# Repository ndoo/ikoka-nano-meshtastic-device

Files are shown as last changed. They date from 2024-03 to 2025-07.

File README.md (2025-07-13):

# Ikoka Nano Meshtastic Device

A Meshtastic device based on the [Seeed Studio XIAO nRF52840](https://www.seeedstudio.com/Seeed-XIAO-BLE-nRF52840-p-5201.html) and EBYTE E22-XXXMXXS series LoRa modules. Pinout matches the [Meshtastic xiao_ble variant](https://github.com/meshtastic/firmware/tree/master/variants/xiao_ble).

The focus is on small size without an onboard display or buttons, meaning it must be used with [Meshtastic client software](https://meshtastic.org/docs/software/), or as a remote repeater managed with [remote node administration](https://meshtastic.org/docs/configuration/remote-admin/).

## Connectors

* USB-C for power and data
* Qwiic connector for I²C sensors
* Battery connectors (PicoBlade 1.25-2P)
* Solar connector (PicoBlade 1.25-2P, 4.45 to 6.45 V - BQ25100 charge IC)

## Libraries Used

* [SnapMagic E22-900M30S footprint & symbol](https://www.snapeda.com/parts/E22-900M30S/EBYTE/view-part/)
* [SparkFun KiCad Libraries](https://github.com/sparkfun/SparkFun-KiCad-Libraries)
* [SeeedStudio OPL KiCad Library](https://github.com/ndoo/OPL_Kicad_Library/tree/xiao-ble-symbols) (forked to add missing XIAO nRF5240 symbol)

## Building One

### Software Required

* The files were created in [KiCad](https://www.kicad.org/) 8
* Clone this git repository recursively, i.e. with `--recursive`

### Ordering PCBs

* Generate the production files
  * Install [kicad-jlcpcb-tools](https://github.com/Bouni/kicad-jlcpcb-tools)
  * Open the PCB file
  * Tools -> External Plugins -> JLCPCB Tools
  * Look over the Bill of Materials list and perform any substitutions required
  * Click Generate
* Order the PCBs
  * Use the Gerbers, BOM and CPL files in `jlcpcb/production_files`
  * Default 1.6mm 2-layer PCB settings should work well, this PCB passes DRC based on JLCPCB specifications (other than the silkscreen of XIAO module being clipped by the PCB edge)

### Ordering Components

* Check the exported BOM file in `jlcpcb/production_files`

### Assembling the PCB

I suggest PCBA, but I used handsoldering pads and all SMDs are 0603 or larger so can be hand-soldered.

1. Solder the SMD components
   * The larger (0805) capacitors go closer to the USB-C connector end of the PCB
2. Solder the connectors
3. Solder the XIAO BLE
   1. It helps to tin the BAT+ pad first, it will help ensure successful soldering through the back. Remove excess solder so that the pad is flat, otherwise the XIAO will not sit flush
   2. Solder one pad first then verify all pads and the battery hole are lined up well, adjust the alignment if necessary
   3. Solder one more pad diagonally opposite, double check the alignment of the pads
   4. Solder the rear hole that goes to the BAT+ pad
   5. Solder the rest of the pads
   6. Test that the XIAO is able to power up from the battery and that charging works (a yellow LED will light up if the battery is charging), you won't be able to access the BAT+ pad once the E22 module is soldered
4. Solder the E22-900M30S module

### Flashing Meshtastic Firmware

#### Pre-built Binaries (Unofficial)

1. [Custom Meshtastic builds web installer](https://mrekin.duckdns.org/flasher/)
2. Select your device -> Xiao BLE
3. Select firmware version -> Pick the latest release
4. Select update or reinstall -> Update device (usually works fine, but if Meshtastic does not start after a few seconds, wipe and reinstall)
5. Download UF2
6. Connect USB-C to PC, double-tap the reset button
7. Drop UF2 file into XIAO-SENSE USB volume

#### Building from Source

Follow the instructions at [meshtastic/firmware/variants/diy/xiao_ble/](https://github.com/meshtastic/firmware/tree/master/variants/diy/xiao_ble).

### Enclosure

A snap-fit 3D printable enclosure is available in the `enclosures` folder. **This has not been updated for the latest board design ([2b17a53](https://github.com/ndoo/ikoka-nano-meshtastic-device/commit/2b17a53b4cfc0f9a9a845ffaf8d8353723f1d552)).**

## PCB Images

rotating

top
bottom

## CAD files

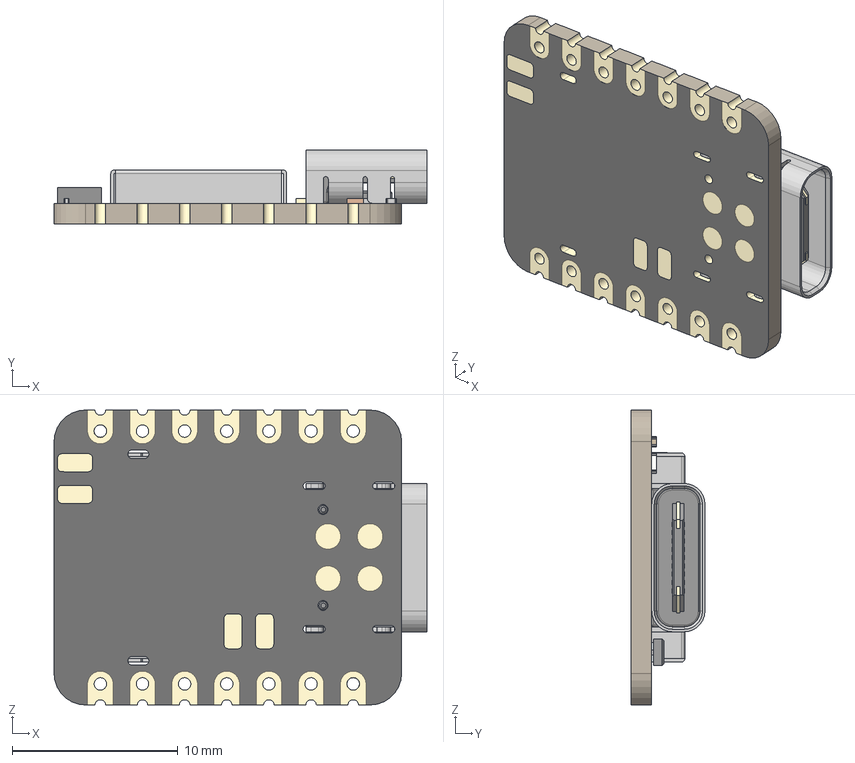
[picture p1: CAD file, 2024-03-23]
3dmodels/XIAO-nRF52840 v15.step
22.5 x 4.46 x 17.8 mm
BOSS-EXTRUDE14_8_
BOSS-EXTRUDE7_4_
BOSS-EXTRUDE7_3_
BOSS-EXTRUDE14_4_
BOSS-EXTRUDE14_2_
BOSS-EXTRUDE14_11_
BOSS-EXTRUDE7_7_
BOSS-EXTRUDE14_9_
BOSS-EXTRUDE14_3_
BOSS-EXTRUDE14_7_
MIRROR2
BOSS-EXTRUDE14_5_
BOSS-EXTRUDE14_12_
BOSS-EXTRUDE7_8_
BOSS-EXTRUDE7_1_
BOSS-EXTRUDE14_10_
BOSS-EXTRUDE7_9_
BOSS-EXTRUDE14_6_
BOSS-EXTRUDE14_1_
BOSS-EXTRUDE7_6_
BOSS-EXTRUDE7_2_
CUT-EXTRUDE5
BOSS-EXTRUDE7_5_
Shield
Pins
CAP x 2
ANT1
Silkscreen
CAP 3
LED
USR
2 v1

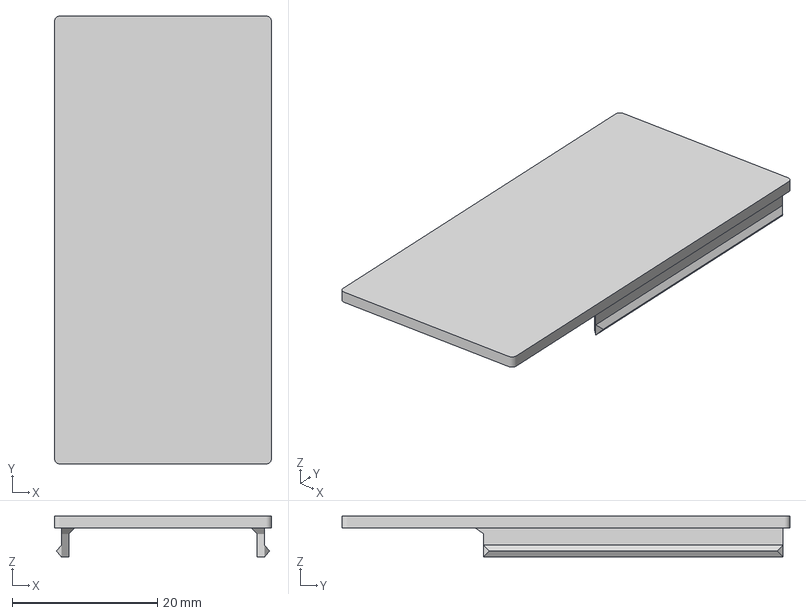
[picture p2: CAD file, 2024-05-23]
enclosure/ikoka nano enclosure lid.3mf
29.9 x 61.7 x 5.60 mm

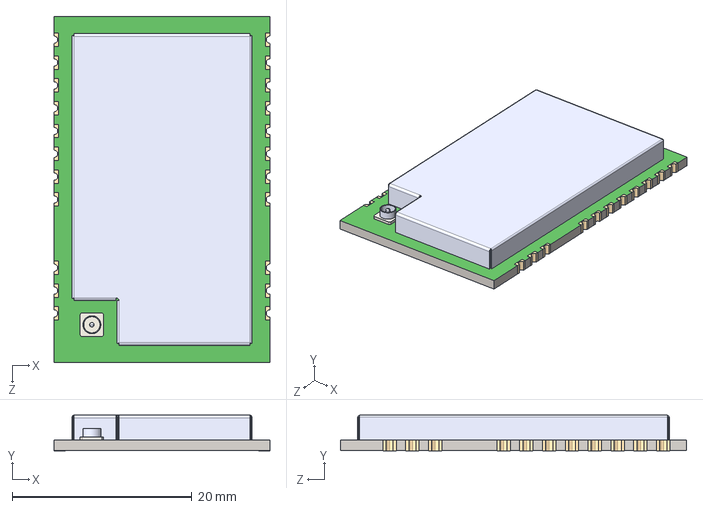
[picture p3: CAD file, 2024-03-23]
symbols/E22-900M30S/E22-900M30S.step
24.0 x 3.97 x 38.5 mm

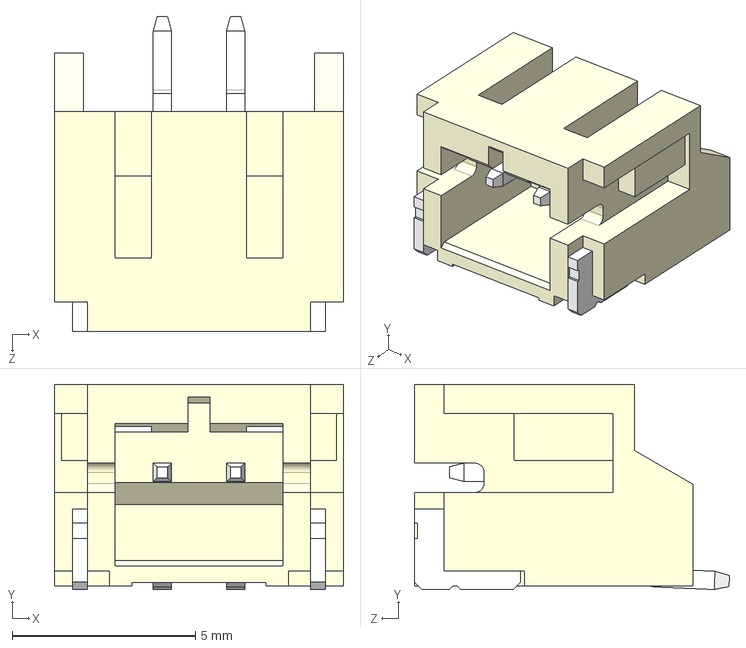
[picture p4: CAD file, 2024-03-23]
3dmodels/S2B-PH-SM4-TB--3DModel-STEP-269445.STEP
7.90 x 5.60 x 8.60 mm

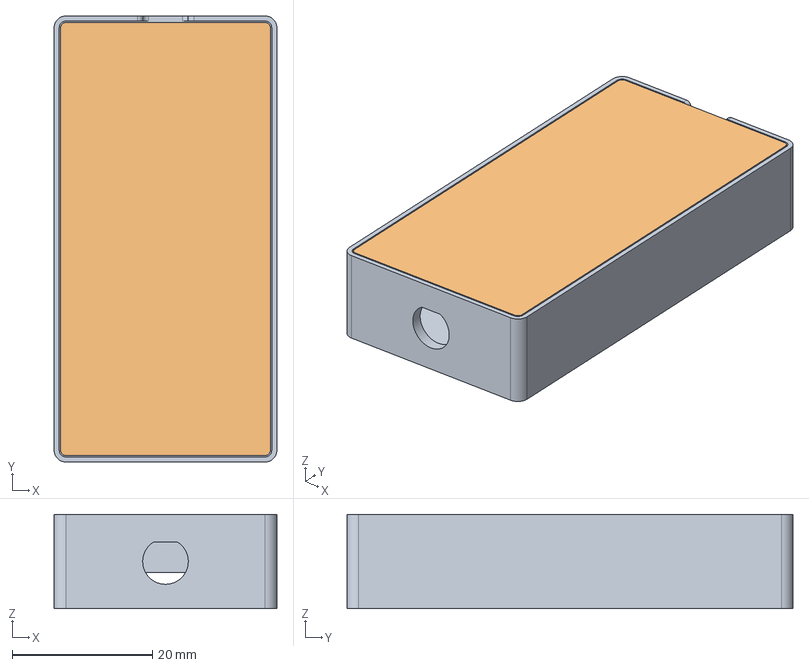
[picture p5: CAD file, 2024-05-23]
enclosure/ikoka nano enclosure.step
31.7 x 63.5 x 13.4 mm

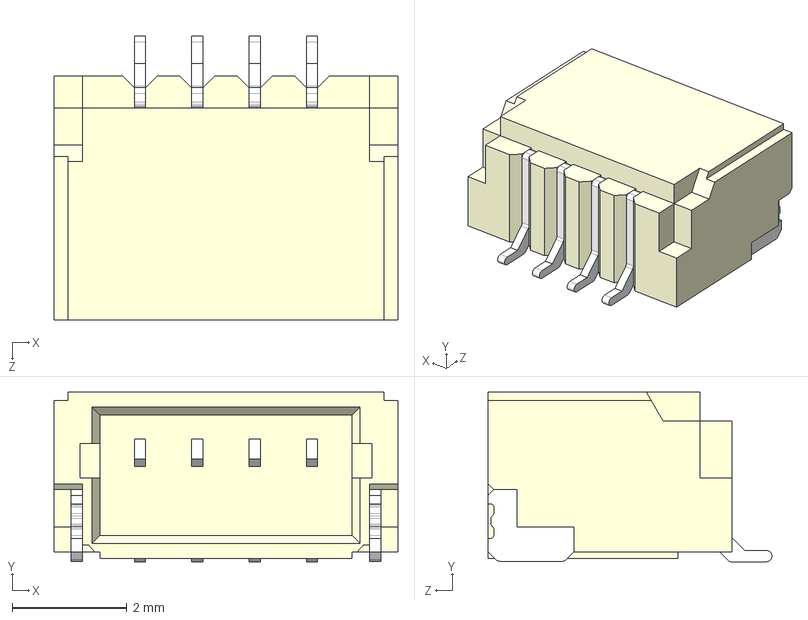
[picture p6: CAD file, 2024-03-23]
3dmodels/SM04B-SRSS-TB(LF)(SN)--3DModel-STEP-269445.STEP
6.00 x 2.96 x 4.95 mm

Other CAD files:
enclosure/ikoka nano enclosure lid.stl
enclosure/ikoka nano enclosure.3mf
enclosure/ikoka nano enclosure.f3d
enclosure/ikoka nano enclosure.stl

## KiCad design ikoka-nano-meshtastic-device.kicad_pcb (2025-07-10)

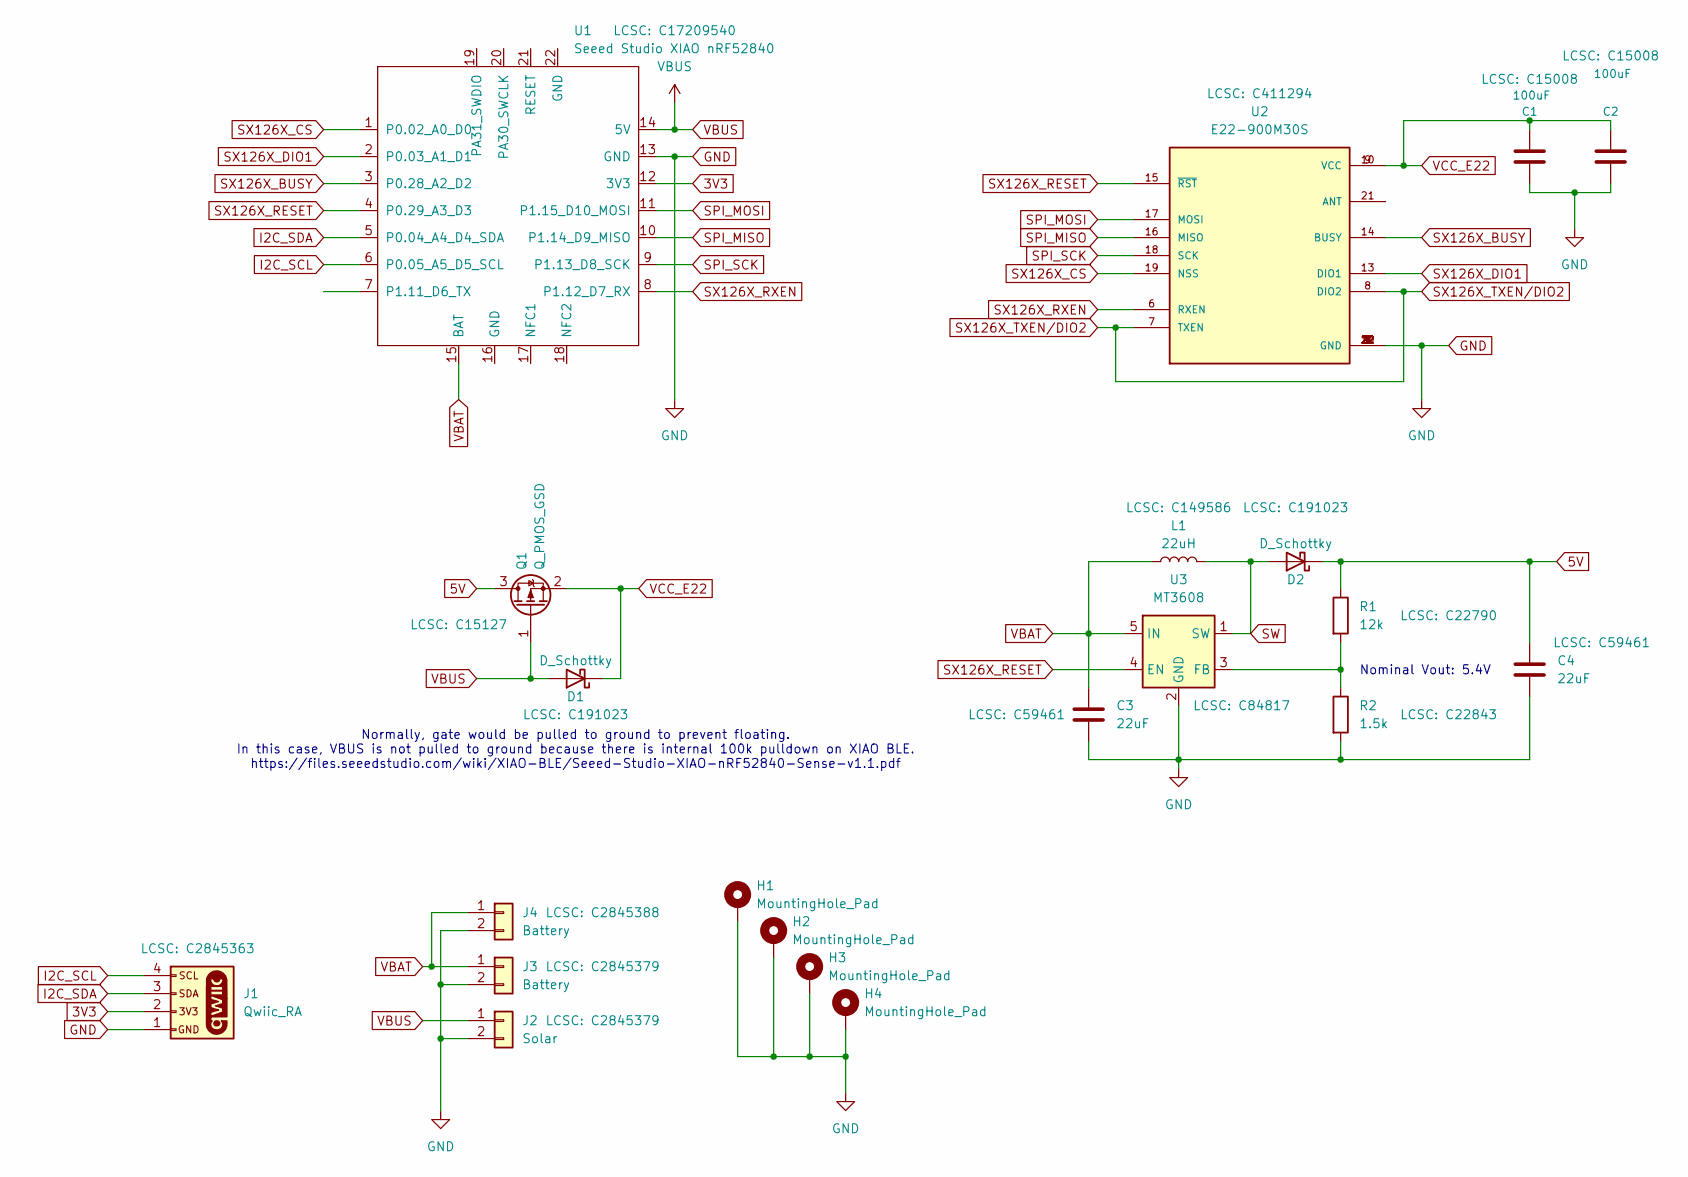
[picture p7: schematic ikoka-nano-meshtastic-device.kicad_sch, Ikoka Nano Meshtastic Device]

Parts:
C1, C2: 100uF; C_1206_3216Metric_Pad1.33x1.80mm_HandSolder; MPN CL31A107MQHNNNE; LCSC C15008
C3, C4: 22uF; C_0603_1608Metric_Pad1.08x0.95mm_HandSolder; MPN CL10A226MQ8NRNC; LCSC C59461
D1, D2: D_Schottky; D_SOD-323_HandSoldering; LCSC C191023
H1, H2, H3, H4: MountingHole_Pad; MountingHole_2.7mm_M2.5_Pad_Via
J1: Qwiic_RA; JST_SMD_1.0mm-4_Black; LCSC C2845363
J2: Solar; Molex_PicoBlade_53261-0271_1x02-1MP_P1.25mm_Horizontal; LCSC C2845379
J3: Battery; Molex_PicoBlade_53261-0271_1x02-1MP_P1.25mm_Horizontal; LCSC C2845379
J4: Battery; Molex_PicoBlade_53398-0271_1x02-1MP_P1.25mm_Vertical; LCSC C2845388
L1: 22uH; L_SXN_SMDRI64; MPN SMMS0650-220M; LCSC C149586
Q1: Q_PMOS_GSD; SOT-23_Handsoldering; LCSC C15127
R1: 12k; R_0603_1608Metric_Pad0.98x0.95mm_HandSolder; MPN 0603WAF1502T5E; LCSC C22790
R2: 1.5k; R_0603_1608Metric_Pad0.98x0.95mm_HandSolder; MPN 0603WAF1871T5E; LCSC C22843
U1: Seeed Studio XIAO nRF52840; XIAO-nRF52840-SMD_Handsoldering; LCSC C17209540
U2: E22-900M30S; XCVR_E22-900M30S; PARTREV 1.2; LCSC C411294
U3: MT3608; SOT-23-6; LCSC C84817

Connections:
3V3: J1.2, U1.12 (3V3)
5V: C4.1, D2.1 (K), Q1.3 (D), R1.1
GND: C1.1, C2.1, C3.2, C4.2, H1.1, H2.1, H3.1, H4.1, J1.1, J2.2, J3.2, J4.2, R2.2, U1.13 (GND), U2.1 (GND), U2.2 (GND), U2.3 (GND), U2.4 (GND), U2.5 (GND), U2.11 (GND), U2.12 (GND), U2.20 (GND), U2.22 (GND), U3.2 (GND)
I2C_SCL: J1.4, U1.6 (P0.05_A5_D5_SCL)
I2C_SDA: J1.3, U1.5 (P0.04_A4_D4_SDA)
unnamed: R1.2, R2.1, U3.3 (FB)
SPI_MISO: U1.10 (P1.14_D9_MISO), U2.16 (MISO)
SPI_MOSI: U1.11 (P1.15_D10_MOSI), U2.17 (MOSI)
SPI_SCK: U1.9 (P1.13_D8_SCK), U2.18 (SCK)
SW: D2.2 (A), L1.2, U3.1 (SW)
SX126X_BUSY: U1.3 (P0.28_A2_D2), U2.14 (BUSY)
SX126X_CS: U1.1 (P0.02_A0_D0), U2.19 (NSS)
SX126X_DIO1: U1.2 (P0.03_A1_D1), U2.13 (DIO1)
SX126X_RESET: U1.4 (P0.29_A3_D3), U2.15 (~RST), U3.4 (EN)
SX126X_RXEN: U1.8 (P1.12_D7_RX), U2.6 (RXEN)
SX126X_TXEN/DIO2: U2.7 (TXEN), U2.8 (DIO2)
VBAT: C3.1, J3.1, J4.1, L1.1, U1.15 (BAT), U3.5 (IN)
VBUS: D1.2 (A), J2.1, Q1.1 (G), U1.14 (5V)
VCC_E22: C1.2, C2.2, D1.1 (K), Q1.2 (S), U2.9 (VCC), U2.10 (VCC)

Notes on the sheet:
Nominal Vout: 5.4V
Normally, gate would be pulled to ground to prevent floating. In this case, VBUS is not pulled to ground because there is internal 100k pulldown on XIAO BLE. https://files.seeedstudio.com/wiki/XIAO-BLE/Seeed-Studio-XIAO-nRF52840-Sense-v1.1.pdf

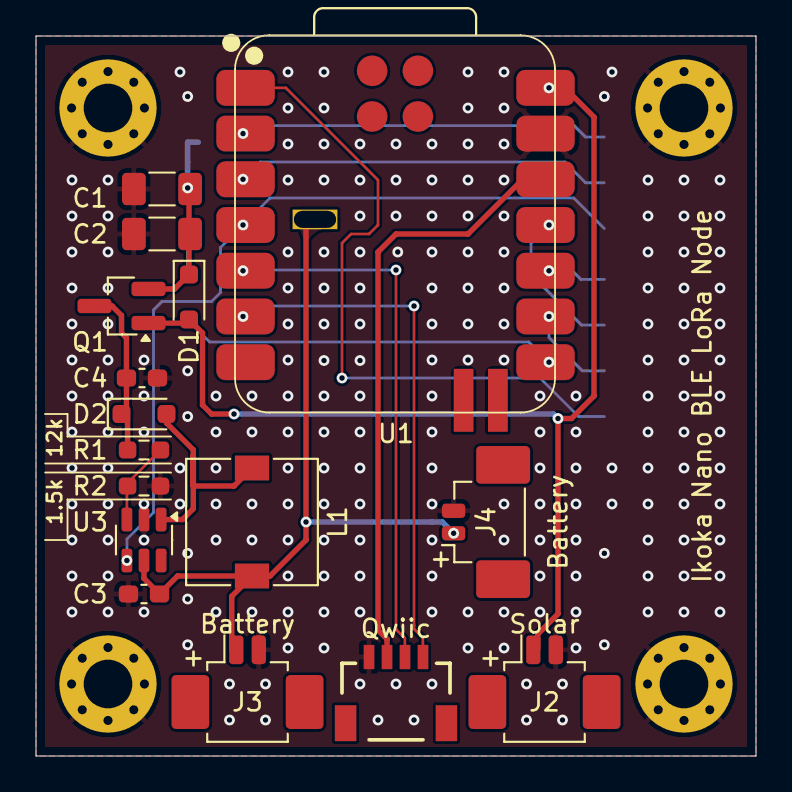
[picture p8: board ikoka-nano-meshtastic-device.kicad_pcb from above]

Board: 2 copper layers, 40.0 x 40.0 mm, 21 parts (1 on the bottom side), 19 nets.

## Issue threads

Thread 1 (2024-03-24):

5V boost regulator for rated output power of E22 module

ndoo, 2024-03-24:
Run the E22 module off a boost converter from VBAT so that E22 PA can achieve full output power. Not sure this will fit in the board footprint though,.

Closed 2025-01-14.

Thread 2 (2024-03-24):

Add cutout to route antenna of E22 to front side

ndoo, 2024-03-24:
Add cutout to route antenna of E22 to front side, for enclosures that will have the E22 module flush to the back of the chassis

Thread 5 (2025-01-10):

Add scematic and other exports for import in Easyeda for self-modifications

tokio69, 2025-01-10:
I want to add some power possibilities to the board, please open the scematic and other files needed to import it in Easyeda

ndoo, 2025-01-10:
Everything you need is in this repository.

tokio69, 2025-01-10:
Not the scematic? Where is that? I only find the Gerber

ndoo, 2025-01-10:
It also says right here in the README that KiCad is required software for this project.

https://github.com/ndoo/ikoka-nano-meshtastic-device?tab=readme-ov-file#software-required

tokio69, 2025-01-11:
Great, I found it to import in EasyEda, just did not know that SCH was the KiCAD file extension for the project since i never used that. This is awesome so thank you

Closed 2025-01-10.

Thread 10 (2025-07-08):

Flashing instructions

tremmert81-tx, 2025-07-08:
Your link to the flashing instructions is not valid:

Follow the instructions at [meshtastic/firmware/variants/xiao_ble/](https://github.com/meshtastic/firmware/tree/master/variants/xiao_ble).

Can you provide the correct link that we should follow?

ndoo, 2025-07-09:
Hi there,

The link broke because of some cleanup in Meshtastic firmware I did.

Here is where the file has moved:

https://github.com/meshtastic/firmware/blob/master/variants/diy/xiao_ble/README.md

I'm not sure if that README is still up-to-date though.

If you already have a build device, what you need to do is download the source of the release that you want on the Meshtastic firmware repo releases page, open it in VS code/PlatformIO, select the xiao_ble variant and build it.

The UF2 file for the firmware can then be found in .pio/build.

Connect the XIAO to your PC and double tap the reset button of the XIAO, a USB disk will appear and you drop the UF2 file in there.

I'll find time to update the README here and in the Meshtastic firmware repo.

ndoo, 2025-07-09:
Hi there @tremmert81-tx,

The README.md in the upstream firmware is very out of date, I have made some improvements to it and raised a PR https://github.com/meshtastic/firmware/pull/7283 to have these changes upstreamed.

You can take a look at my new README.md for xiao_ble here, at least, until it gets accepted into upstream, at which point I may delete my branch: https://github.com/ndoo/meshtastic-firmware/blob/xiao_ble-readme/variants/diy/xiao_ble/README.md

Once it's merged into upstream, I'll update the link in this repo.

Thanks for your patience.

Closed 2025-07-13.

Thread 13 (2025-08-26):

Compatibilty with 33S modules

KevinGaudry, 2025-08-26:
Hello,

First of all, thanks for the work done, looks tidy.

I was reading some other projects and there was a step to take care of when using this 33db module, reducing power to 9db during first setup.
Is this still the case or has this been fixed in code ? I am not qualified enough to check unfortunately...

Other than this, the PCB files and CPL+BOM which I can download in the latest version are just good to go or shall I wait another release ?

Thanks for the support,
Kevin

ndoo, 2025-08-26:
It's taken care of in code, use the firmware variant that ends in 900m33s; you can build it yourself or obtain binaries here: https://mrekin.duckdns.org/flasher/

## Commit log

2024-03-23 Redesign board because the E22-900M22S footprint from SnapMagic was much smaller than the actual module size; add solar 5V connector; reduce Qwiic connectors to just one.
    [ikoka-nano.brd, ikoka-nano.sch]
2024-03-23 Update README and add PCB images
2024-03-23 Add project name and ndoo.sg to board front
    [ikoka-nano.brd]
2024-03-23 Move some values to names layer to ensure JLCPCB CAM generates silkscreen; hide U1/U2 value under components
    [ikoka-nano.brd]
2024-03-23 Update PCB images
2024-03-23 Update schematic with LCSC part numbers
    [ikoka-nano-meshtastic-device.kicad_pcb, ikoka-nano-meshtastic-device.kicad_sch]
2024-03-23 Update board images to be non-perspective views
2024-03-23 Add generated Gerbers/BOM for JLCPCB
    [ikoka-nano-meshtastic-device-B_Cu.gbl, ikoka-nano-meshtastic-device-B_Mask.gbs, ikoka-nano-meshtastic-device-B_Paste.gbp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]
2024-03-23 Update ground plane stitching and related generated artifacts; bump PCB revision to 1.1
    [ikoka-nano-meshtastic-device-B_Cu.gbl, ikoka-nano-meshtastic-device-B_Mask.gbs, ikoka-nano-meshtastic-device-B_Paste.gbp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]
2024-05-09 Power EBYTE E22 module from 5V and remove JST-PH 2.0 connectors
    Power EBYTE E22 module from 5V because VBAT results in very poor transmit power.
    Remove JST connectors since the device no longer functions without 5V.
    [ikoka-nano-meshtastic-device.kicad_pcb, ikoka-nano-meshtastic-device.kicad_sch]
2024-05-09 Update footprints table
2024-05-09 Add kicad-render GitHub action
    Add kicad-render GitHub action from [linalinn/kicad-render](https://github.com/linalinn/kicad-render)
    [ikoka-nano-meshtastic-device-B_Cu.gbl, ikoka-nano-meshtastic-device-B_Mask.gbs, ikoka-nano-meshtastic-device-B_Paste.gbp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]
2024-05-09 Update README for KiCad 8 and rendered images
2024-05-09 Update .gitignore to ignore KiCad 8 lock files
2024-05-11 Update README.md and remove repo board images
2024-05-23 Update README to remove reference to battery and solar power.
2024-05-23 enclosure: Add 3D printable enclosure and update README
    [ikoka nano enclosure lid.3mf, ikoka nano enclosure lid.stl, ikoka nano enclosure.3mf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]
2024-05-23 Remove gerbers, use README instructions to generate them on demand
2024-11-28 Add Molex Picoblade 1.25x2 connectors for VBAT and VBUS, add load switch for E22 module power
    [ikoka-nano-meshtastic-device.kicad_pcb, ikoka-nano-meshtastic-device.kicad_sch]
2024-11-28 Add missing D1 footprint and update PCB; add LCSC part numbers; remove gerbers
    [ikoka-nano-meshtastic-device.kicad_pcb, ikoka-nano-meshtastic-device.kicad_sch]
2024-11-28 Increase VBAT via size and add teardrop
    [ikoka-nano-meshtastic-device.kicad_pcb]
2024-11-28 Fix part attributes for LCSC PN and make compatible with latest JLCPCB fabrication toolkit
    [ikoka-nano-meshtastic-device.kicad_pcb, ikoka-nano-meshtastic-device.kicad_sch]
2024-11-29 Add LCSC PN display for C1, clean up production folder again
    [ikoka-nano-meshtastic-device.kicad_pcb, ikoka-nano-meshtastic-device.kicad_sch]
2024-12-03 Branch Seeed OPL Kicad library to modify XIAO nRF52840 Library
2024-12-03 Update Seeed XIAO nRF52840 with BAT+ PTH pad
    [ikoka-nano-meshtastic-device.kicad_pcb, ikoka-nano-meshtastic-device.kicad_sch]
2024-12-10 Switch back to SparkFun Qwiic symbol/footprint, run DRC, fix 3D models
    [ikoka-nano-meshtastic-device.kicad_pcb, ikoka-nano-meshtastic-device.kicad_sch]
2024-12-10 Rebase XIAO BLE hand soldering symbol/footprint on upstream
    [ikoka-nano-meshtastic-device.kicad_pcb, ikoka-nano-meshtastic-device.kicad_sch]
2025-02-27 Sync symbol libraries
    [ikoka-nano-meshtastic-device.kicad_pcb, ikoka-nano-meshtastic-device.kicad_sch]
2025-07-10 Add 5.4V boost converter circuit, use more JLCPCB basic parts, make PCB square, add internal battery connector
    [ikoka-nano-meshtastic-device.kicad_pcb, ikoka-nano-meshtastic-device.kicad_sch]
2025-07-10 Use AO3401A PMOS which is JLCPCB basic part
    [ikoka-nano-meshtastic-device.kicad_pcb, ikoka-nano-meshtastic-device.kicad_sch]
2025-07-10 Add カモノハシのイコちゃん silkscreen
    [ikoka-nano-meshtastic-device.kicad_pcb]
2025-07-10 chore: Sync footprint libraries
    [ikoka-nano-meshtastic-device.kicad_pcb, ikoka-nano-meshtastic-device.kicad_sch]
2025-07-10 chore(GitHub): Fix pcb_image workflow
2025-07-10 feat: Improve DC-DC converter and power path
    - Update R1 and R2 resistors to match Ikoka Handheld values (300kΩ, 39kΩ respectively)
    - Change E22 capacitors to 2x 47µF instead of 2x 100µF
    - Change P-MOSFET load switch to switch input to DC-DC boost so that E22 supply is constant even when switching to USB power
    - Add 300k pulldown on MT3608L enable pin to prevent it floating when Meshtastic firmware is not running
    - Layout for above changes
    - Move connectors flush with PCB edge
    Fixes #11
    [ikoka-nano-meshtastic-device.kicad_pcb, ikoka-nano-meshtastic-device.kicad_sch]
2025-07-10 chore: Use correct Kicad connector symbols and ground MountingPins
    [ikoka-nano-meshtastic-device.kicad_pcb, ikoka-nano-meshtastic-device.kicad_sch]
2025-07-10 fix(pcbnew): Set XIAO footprint type to SMD
    [ikoka-nano-meshtastic-device.kicad_pcb]
2025-07-10 fix(pcbnew): XIAO 3dmodel path was incorrect
    [ikoka-nano-meshtastic-device.kicad_pcb]
2025-07-13 Update README.md
    - Update "Assembling the PCB"
    - Update "Flashing Meshtastic Firmware" (fixes #10)
2025-07-15 feat: Improve boost converter part selection
    - Change inductor from 22uH FNR4026S220MT to 2.2uH FXL0420-2R2-M
    - Change MT3608L to MT3608B
    [ikoka-nano-meshtastic-device.kicad_pcb, ikoka-nano-meshtastic-device.kicad_sch]
